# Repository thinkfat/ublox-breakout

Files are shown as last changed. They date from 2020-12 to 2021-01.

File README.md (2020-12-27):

ublox-breakout
==============

This is a breakout board for LEA (and eventually NEO) M8 Ublox GNSS modules.
Its main features are:
- 12 contact pin header for signals
- Micro USB receptacle
- 5V power supply via USB or pin header
- buffered PPS output with SMA receptacle
- small size 47.2mm x 33.2mm
- support for active GPS antenna with 3.3V bias voltage
- 4 mounting holes for M2.5 screws or stand-offs.
- EDS protection for antenna input
- Clip for CR1220 backup battery

This repository contains a KiCAD 5 project with schematic and PCB. The **fab** folder
contains the Gerber files and also BOM and CPL files for JLCPCB SMT service. If you
order the board, make sure to check "Impedance control" and use the JLC7628 stack-up.

All SMT parts are in JLCPCBs SMT library, except for the USB receptacle, battery clip and
antenna input ESD protection diode.
- USB: Molex 47346-0001
- Battery clip: Keystone 3000
- ESD diode: ONsemi ESD9R3.3ST5G

The mounting hole centers are offset 3mm from the board edges.

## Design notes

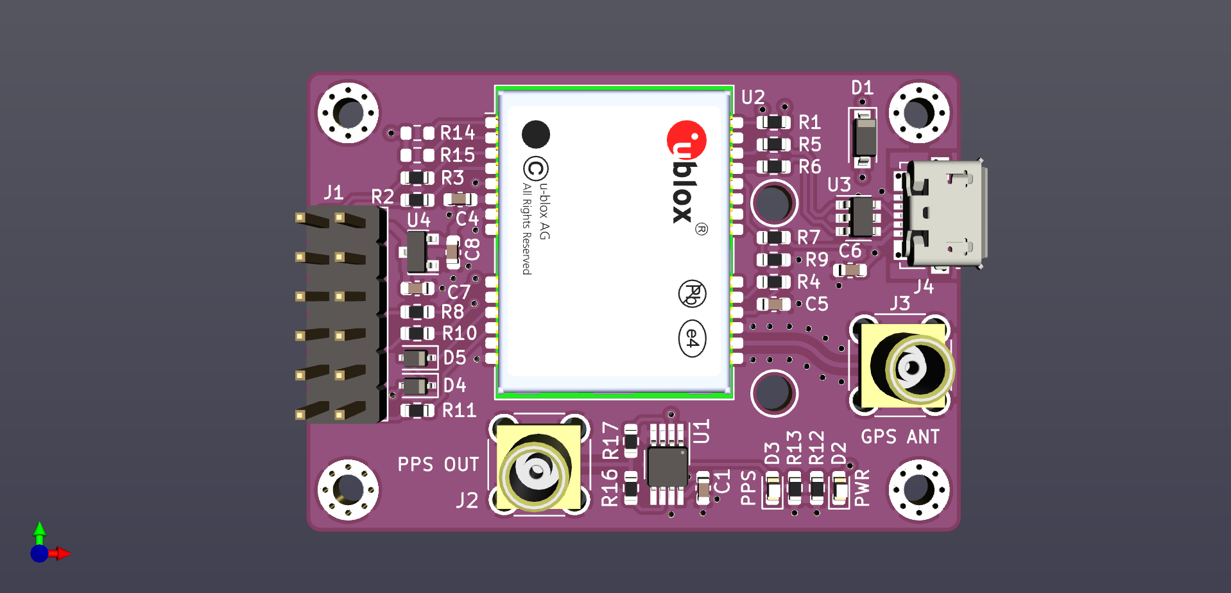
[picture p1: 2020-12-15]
doc/ublox-breakout.png

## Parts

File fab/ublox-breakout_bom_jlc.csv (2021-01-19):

Comment | Designator | Footprint | LCSC Part #
100n | C1,C9 | C_0603_1608Metric | C14663
10u | C2 | CP_EIA-3216-18_Kemet-A | C7171
1u | C4,C6,C7,C8,C3 | C_0603_1608Metric | C29936
10n | C5 | C_0603_1608Metric | C57112
1n | C10 | C_0603_1608Metric | C1588
B5819W | D1 | D_SOD-123 | C8598
LED Green | D2 | LED_0603_1608Metric | C72043
LED Red | D3 | LED_0603_1608Metric | C2286
1N4148WS | D4 | D_SOD-323 | C2128
BAT54HT1G | D5 | D_SOD-323 | C21107
PESD5V0U1UA,115 | D7 | D_SOD-323 | C139614
27 | R2,R3,R1,R5,R6,R10,R11,R8 | R_0603_1608Metric | C25190
10 | R4 | R_0603_1608Metric | C22859
2.7k | R7 | R_0603_1608Metric | C13167
100k | R9 | R_0603_1608Metric | C25803
680 | R12,R13,R18 | R_0603_1608Metric | C23228
82 | R16,R17 | R_0603_1608Metric | C23255
NC7SZ125 | U1,U6 | SOT-353_SC-70-5 | C112084
USBLC6-4SC6 | U3 | SOT-23-6 | C111212
XC6206P332MR | U4,U5 | SOT-23 | C5446

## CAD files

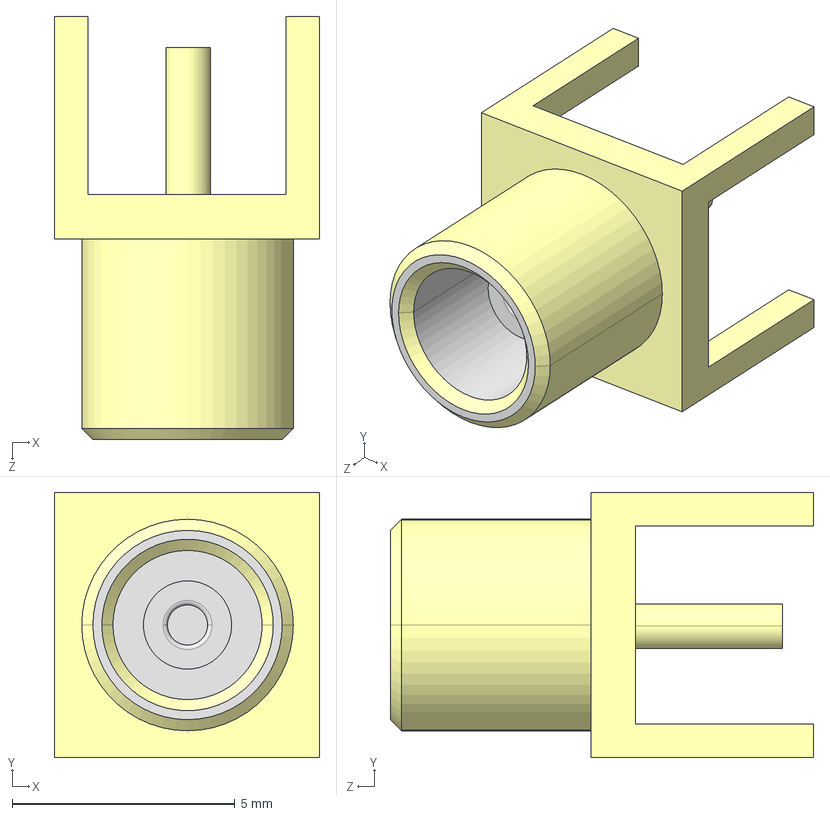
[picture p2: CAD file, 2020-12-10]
User Library-MCX_Plug_Straight.step
5.95 x 5.95 x 9.50 mm

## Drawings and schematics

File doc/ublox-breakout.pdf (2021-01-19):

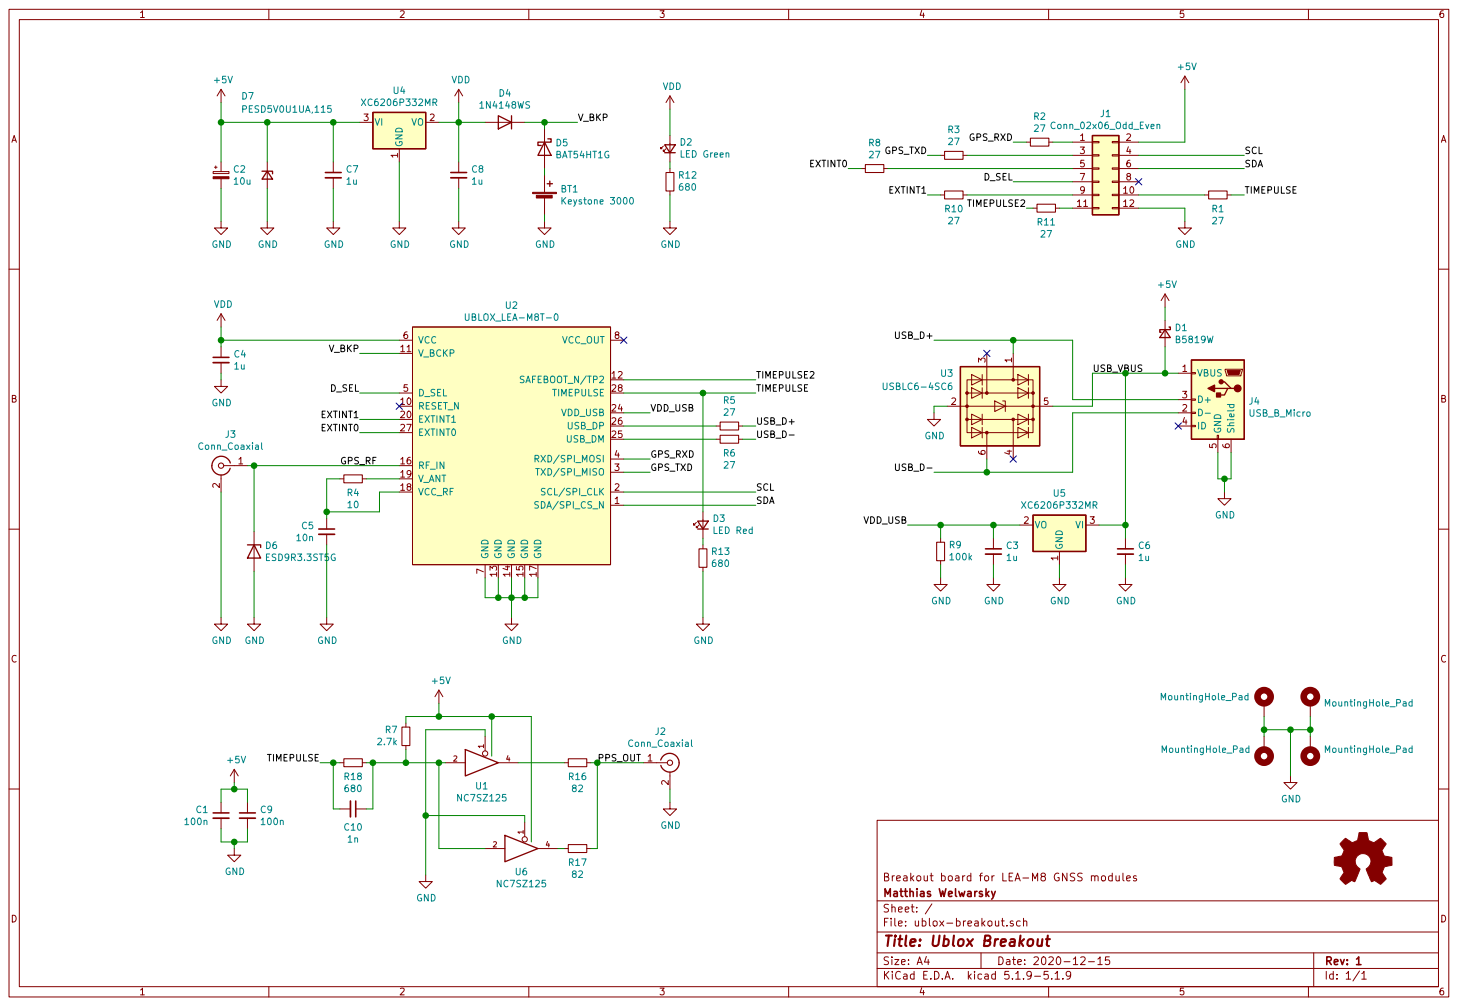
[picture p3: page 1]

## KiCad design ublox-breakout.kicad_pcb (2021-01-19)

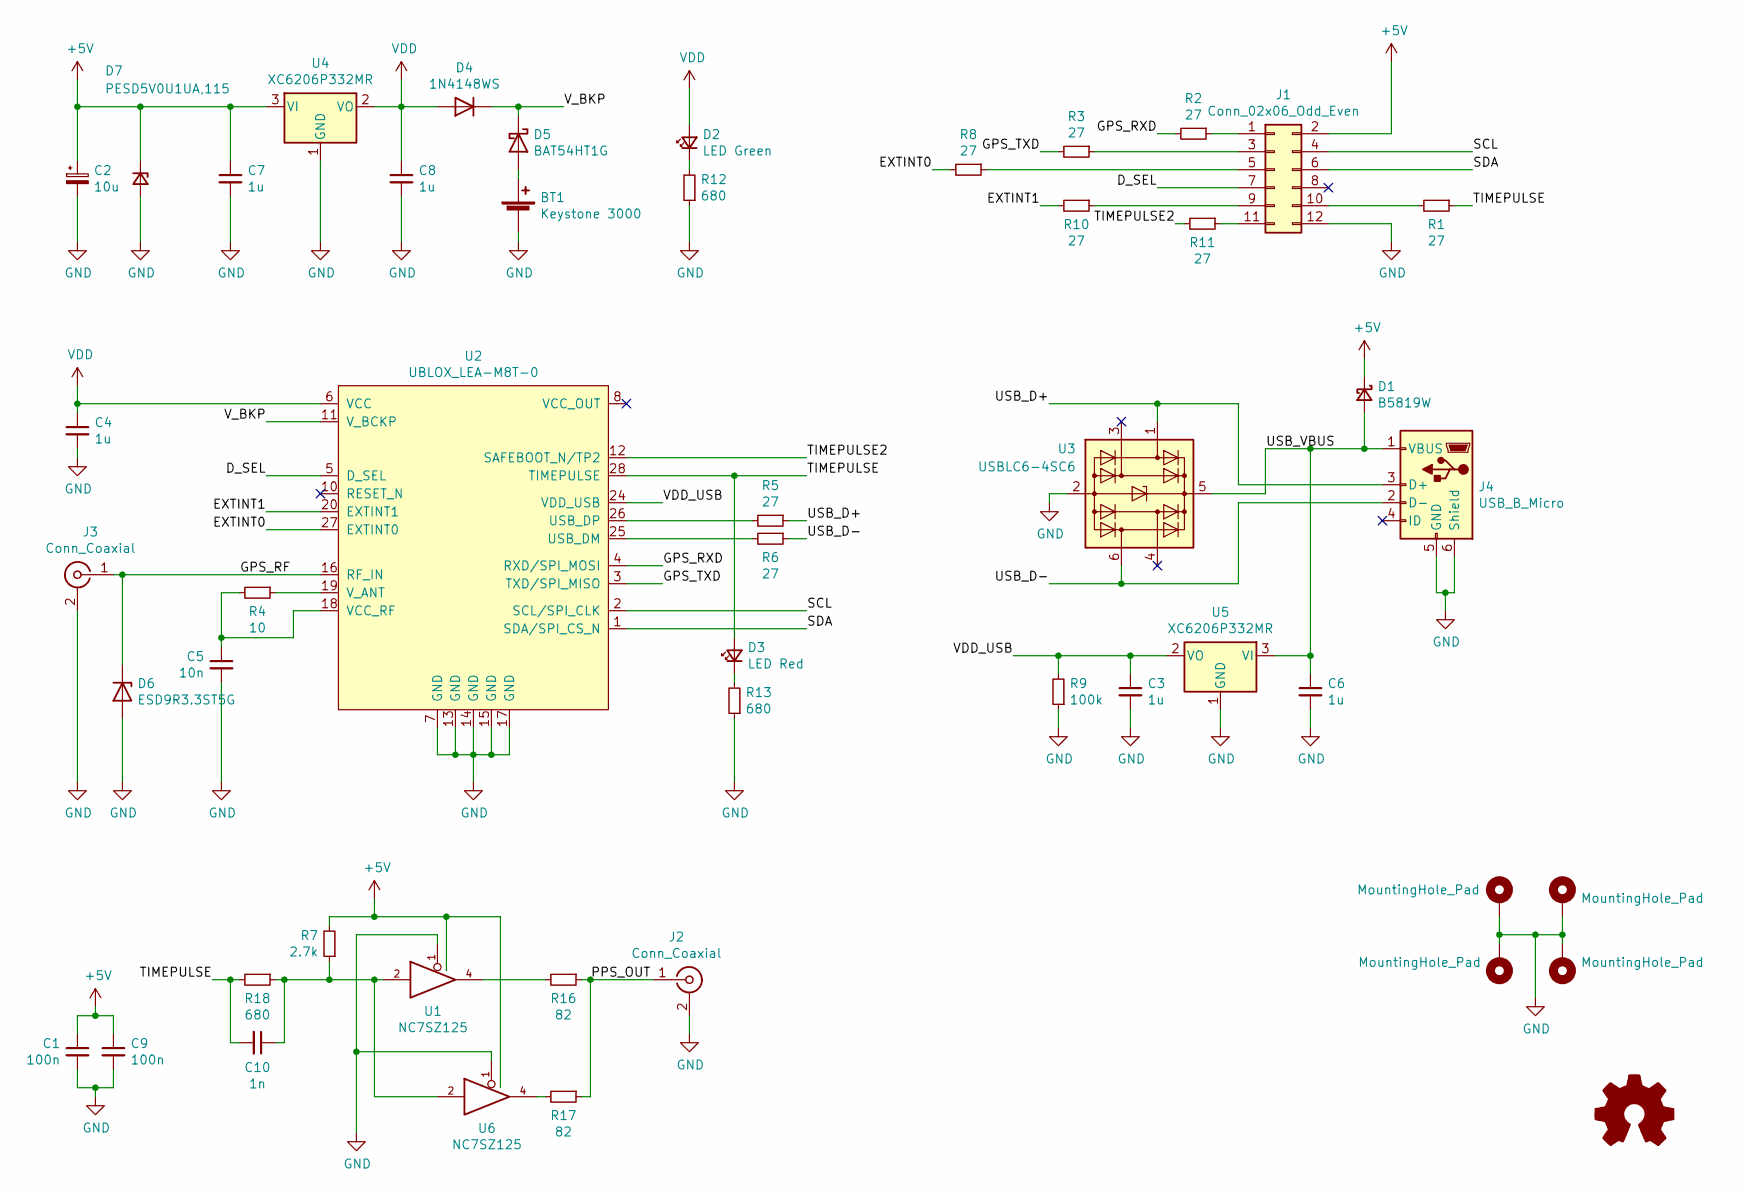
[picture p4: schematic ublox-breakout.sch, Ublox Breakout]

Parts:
BT1: Keystone 3000; BatteryHolder_Keystone_3000_1x12mm
C1, C9: 100n; C_0603_1608Metric; JLCPN C14663
C2: 10u; CP_EIA-3216-18_Kemet-A; JLCPN C7171
C3, C4, C6, C7, C8: 1u; C_0603_1608Metric; JLCPN C29936
C5: 10n; C_0603_1608Metric; MPN 0603B103K500NT; JLCPN C57112
C10: 1n; C_0603_1608Metric; JLCPN C1588
D1: B5819W; D_SOD-123; MPN B5819W; JLCPN C8598
D2: LED Green; LED_0603_1608Metric; JLCPN C72043
D3: LED Red; LED_0603_1608Metric; JLCPN C2286
D4: 1N4148WS; D_SOD-323; JLCPN C2128
D5: BAT54HT1G; D_SOD-323; JLCPN C21107
D6: ESD9R3.3ST5G; D_SOD-923
D7: PESD5V0U1UA,115; D_SOD-323; JLCPN C139614
H1, H2, H3, H4: MountingHole_Pad; MountingHole_2.2mm_M2_Pad_Via
J1: Conn_02x06_Odd_Even; PinHeader_2x06_P2.54mm_Vertical
J2, J3: Conn_Coaxial; SMA_Amphenol_132134_Vertical
J4: USB_B_Micro; USB_Micro-B_Molex_47346-0001
OSHW1: Logo_Open_Hardware_Small; OSHW-Logo2_9.8x8mm_SilkScreen
R1, R2, R3, R5, R6, R8, R10, R11: 27; R_0603_1608Metric; JLCPN C25190
R4: 10; R_0603_1608Metric; JLCPN C22859
R7: 2.7k; R_0603_1608Metric; JLCPN C13167
R9: 100k; R_0603_1608Metric; JLCPN C25803
R12, R13, R18: 680; R_0603_1608Metric; JLCPN C23228
R16, R17: 82; R_0603_1608Metric; JLCPN C23255
U1, U6: NC7SZ125; SOT-353_SC-70-5; JLCPN C112084
U2: UBLOX_LEA-M8T-0; ublox_LEA
U3: USBLC6-4SC6; SOT-23-6; JLCPN C111212
U4, U5: XC6206P332MR; SOT-23; JLCPN C5446

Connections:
+5V: C1.1, C2.1, C7.1, C9.1, D1.1 (K), D7.1 (K), J1.2, R7.2, U1.5 (VCC), U4.3 (VI), U6.5 (VCC)
/D_SEL: J1.7, U2.5 (D_SEL)
/EXTINT0: R8.2, U2.27 (EXTINT0)
/EXTINT1: R10.2, U2.20 (EXTINT1)
/GPS_RF: D6.1 (K), J3.1 (In), U2.16 (RF_IN)
/GPS_RXD: R2.2, U2.4 (RXD/SPI_MOSI)
/GPS_TXD: R3.2, U2.3 (TXD/SPI_MISO)
/PPS_OUT: J2.1 (In), R16.1, R17.1
/SCL: J1.4, U2.2 (SCL/SPI_CLK)
/SDA: J1.6, U2.1 (SDA/SPI_CS_N)
/TIMEPULSE: C10.2, D3.2 (A), R1.1, R18.2, U2.28 (TIMEPULSE)
/TIMEPULSE2: R11.2, U2.12 (SAFEBOOT_N/TP2)
/USB_D+: J4.3 (D+), R5.1, U3.1 (I/O1)
/USB_D-: J4.2 (D-), R6.1, U3.6 (I/O4)
/USB_VBUS: C6.1, D1.2 (A), J4.1 (VBUS), U3.5 (VBUS), U5.3 (VI)
/VDD_USB: C3.1, R9.2, U2.24 (VDD_USB), U5.2 (VO)
/V_BKP: D4.1 (K), D5.1 (K), U2.11 (V_BCKP)
GND: BT1.2 (-), C1.2, C2.2, C3.2, C4.2, C5.2, C6.2, C7.2, C8.2, C9.2, D6.2 (A), D7.2 (A), H1.1, H2.1, H3.1, H4.1, J1.12, J2.2 (Ext), J3.2 (Ext), J4.5 (GND), J4.6 (Shield), R9.1, R12.1, R13.1, U1.1, U1.3 (GND), U2.7 (GND), U2.13 (GND), U2.14 (GND), U2.15 (GND), U2.17 (GND), U3.2 (GND), U4.1 (GND), U5.1 (GND), U6.1, U6.3 (GND)
unnamed: BT1.1 (+), D5.2 (A)
unnamed: C5.1, R4.2, U2.18 (VCC_RF)
unnamed: C10.1, R7.1, R18.1, U1.2, U6.2
unnamed: D2.1 (K), R12.2
unnamed: D3.1 (K), R13.2
unnamed: J1.1, R2.1
unnamed: J1.3, R3.1
unnamed: J1.5, R8.1
unnamed: J1.9, R10.1
unnamed: J1.10, R1.2
unnamed: J1.11, R11.1
unnamed: R4.1, U2.19 (V_ANT)
unnamed: R5.2, U2.26 (USB_DP)
unnamed: R6.2, U2.25 (USB_DM)
unnamed: R16.2, U1.4
unnamed: R17.2, U6.4
VDD: C4.1, C8.1, D2.2 (A), D4.2 (A), U2.6 (VCC), U4.2 (VO)

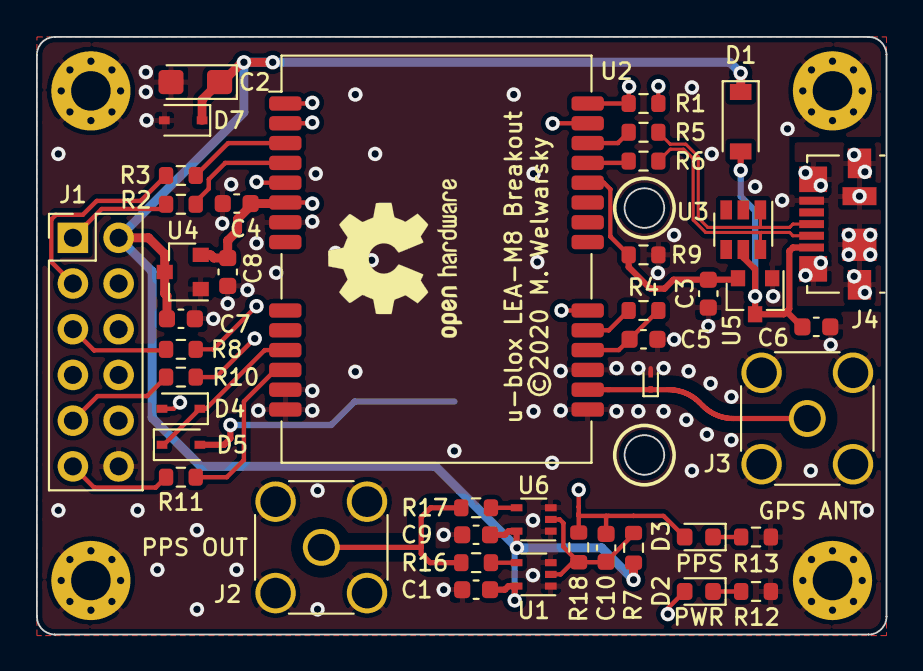
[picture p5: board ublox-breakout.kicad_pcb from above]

Board: 4 copper layers, 47.2 x 33.2 mm, 49 parts (1 on the bottom side), 35 nets.

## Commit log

2020-12-10 Initial commit
    Breakout PCB for UBlox M8T GNSS receiver
    [User Library-MCX_Plug_Straight.step, ublox-breakout.kicad_pcb, ublox-breakout.sch]
2020-12-12 Prototype LEA-M8 breakout board
    includes fabrication Gerber files and BOM+CPL files for
    JLCPCB SMT service.
    PCB must be ordered with impedance control JLC7628 stack-up
    [ublox-breakout-B_Cu.gbl, ublox-breakout-B_Mask.gbs, ublox-breakout-B_Paste.gbp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]
2020-12-14 Update LEA breakout board:
    - add backup battery
    - add buffered PPS output
    - add pull-up resistors for SCL/SDA
    - add D_SEL on pin header
    [ublox-breakout-B_Cu.gbl, ublox-breakout-B_Mask.gbs, ublox-breakout-B_Paste.gbp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]
2020-12-15 BOM and schematic updates
    - mark I2C pull-ups DNP (module has built-in pull resistors)
    - small schematic cleanups
    - add schematic PDF and board image
    - update fabrication data
    [ublox-breakout-B_Cu.gbl, ublox-breakout-B_Mask.gbs, ublox-breakout-B_Paste.gbp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]
2020-12-15 PCB and schematic updates
    - change backup battery circuit to prevent inverse current
    - add bulk capacitor to +5V rail
    - add ESD protection diode for RF input
    [ublox-breakout-B_Cu.gbl, ublox-breakout-B_Mask.gbs, ublox-breakout-B_Paste.gbp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]
2020-12-27 Fix USB and other issues
    - use an LDO to provide VDD_USB as per HIM (major issue)
    - correct trace width for GPS antenna input (minor issue)
    - add OSHW logo on top silk
    - add copyright notice on top silk
    - update gerber, BOM and CPL files
    - update schematic PDF
    [ublox-breakout-B_Cu.gbl, ublox-breakout-B_Mask.gbs, ublox-breakout-B_Paste.gbp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]
2021-01-02 USB updates and 1PPS updates
    These changes make the USB ESD protection fully optional since the
    USBLC6-2SC6 is frequently out of stock at JLCPCB
    - replace USBLC6-2SC6 with USBLC6-4SC6
    - route a 7mil/4mil differential pair under its body and connect it
    Tighter coupling of the 74HCT2G125 buffer to the SMA connector to
    bring the impedance closer to 50 Ohm
    [ublox-breakout-B_Cu.gbl, ublox-breakout-B_Mask.gbs, ublox-breakout-B_Paste.gbp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]
2021-01-05 Update PPS output buffer
    Change output buffer to 2*NC7SZ125, add a small resistor network
    to lift the input signal from 3.3V LVC to standard 5V CMOS
    [ublox-breakout-B_Cu.gbl, ublox-breakout-B_Mask.gbs, ublox-breakout-B_Paste.gbp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]
2021-01-19 Overvoltage and R.P. protection, PPS buffer updates
    Added an ESD diode at the input to protect the bulk
    decoupling capacitor (tantalum). It's unidirectional and provides
    at least some reverse polarity protection as well (will short out).
    Faster rise time at input gate of PPS buffers by adding a small
    10nF capacitor
    Move USB ESD protection a bit to make soldering the USB receptacle
    easier
    [ublox-breakout-B_Cu.gbl, ublox-breakout-B_Mask.gbs, ublox-breakout-B_Paste.gbp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]

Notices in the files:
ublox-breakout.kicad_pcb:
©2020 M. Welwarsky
